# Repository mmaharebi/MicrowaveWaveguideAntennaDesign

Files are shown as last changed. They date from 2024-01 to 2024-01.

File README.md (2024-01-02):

# Microwave and Optical Design Lab Project 1

## Introduction
This project aims to provide a hands-on experience with the concepts and methods of matching in waveguide circuits, utilizing various discontinuities such as capacitive and inductive irises and E-plane posts. The designs were simulated and measured using HFSS software and AutoCAD.

## Experiments

### Experiment 1: Two-port iris structures
- **Objective**: Simulate and analyze the frequency response of a waveguide circuit with two assigned irises.
- **Steps**:
  1. Open AutoCAD files (`dwg1._3EXP_StudentID`) for iris designs.
  2. Simulate transmission and reflection coefficients in the 8-12 GHz range.
  3. Extract the circuit model using S-parameters and transmission line model.
  4. Use embedding-deembedding technique to compensate for extra lengths.

### Experiment 2: Open-ended waveguide antenna with an iris
- **Objective**: Measure reflection coefficient, compare results with Experiment 1, and analyze radiation patterns.
- **Steps**:
  1. Open AutoCAD files (`dwg1._3EXP_StudentID`) for iris designs.
  2. Measure reflection coefficient with absorbing boundary condition.
  3. Find the circuit model using measured reflection coefficient and transmission line model.
  4. Compare results with Experiment 1 and explain admittance differences.
  5. Calculate and plot realized gain pattern and beamwidth in E and H planes.

### Experiment 3: Matching the open-ended waveguide antenna with E-plane posts
- **Objective**: Match the waveguide antenna with metallic posts, analyze bandwidth, and radiation parameters.
- **Steps**:
  1. Open AutoCAD files (`dwg2._3EXP_StudentID`, `dwg3._3EXP_StudentID`) for post designs.
  2. Measure reflection coefficient with absorbing boundary condition.
  3. Use single-stub matching on the Smith chart to determine post distance and required admittance.
  4. Implement required admittance by designing post width using HFSS and plot admittance versus width curve.
  5. Plot frequency response, report 15 dB bandwidth, and optionally improve bandwidth with more posts.
  6. Calculate and plot realized gain pattern and beamwidth, comparing with unmatched antenna. Explain the effect of matching on radiation parameters.

## Submission
- Ensure that AutoCAD files for iris and post designs are named according to the provided format.
- Include a detailed report covering simulations, measurements, calculations, and plots for each experiment.
- Explain observations, comparisons, and the impact of matching on radiation parameters.

## How to Reproduce
1. Clone the repository: `git clone https://github.com/your-username/your-project.git`
2. Open AutoCAD files for iris and post designs.
3. Follow instructions in the README to reproduce each experiment.
4. Submit your results and report following the guidelines provided in the Submission section.

Feel free to reach out for any clarifications or assistance!

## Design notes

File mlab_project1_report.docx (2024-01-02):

به نام خدا

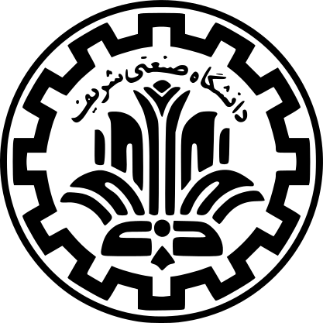
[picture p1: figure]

دانشگاه صنعتی شریف

دانشکده مهندسی برق

گزارش پروژه اول درس آزمایشگاه طراحی و ساخت مایکروویو و نوری

استاد درس:

دکتر علی بنایی

نگارش:

محمدمهدی محاربی

# آزمایش شماره 1

## الف

ساختار شبیه‌سازی در شکل 1 آورده شده است.

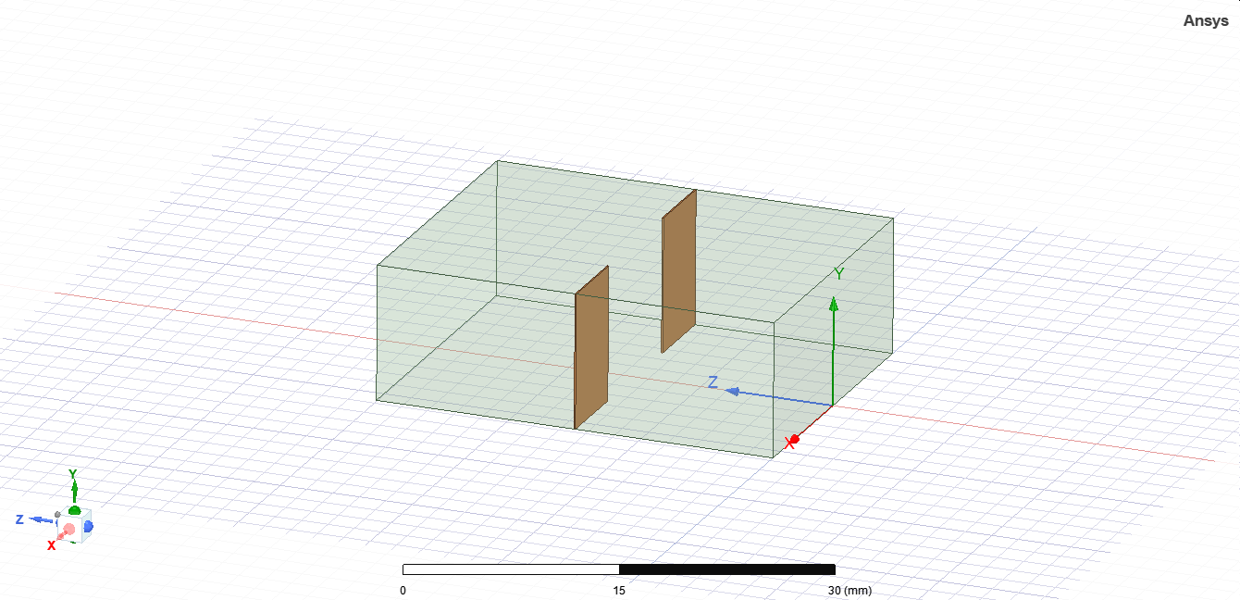
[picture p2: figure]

شکل 1 ساختار شبیه‌سازی آزمایش شماره 1

## ب

نمودار پاسخ فرکانسی اندازه افت عبوری و افت بازگشتی برحسب مقیاس dB ، پس از اعمال de-embedding بر پارامترهای پراکندگی در نمودارهای شکل 2 و شکل 3 آورده شده است.

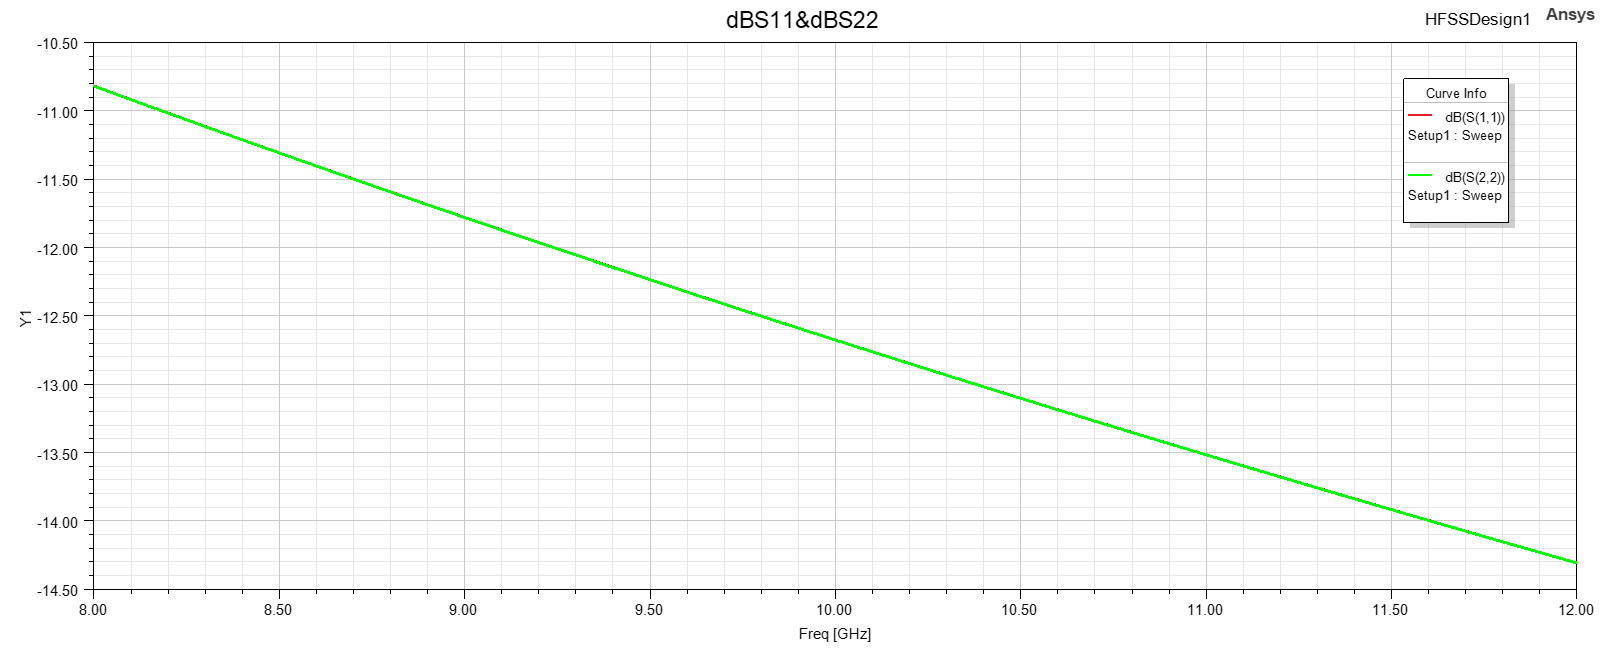
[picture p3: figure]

شکل 2 نمودار پاسخ فرکانسی اندازه افت بازگشتی برحسب مقیاس dB در پورت 1 و 2

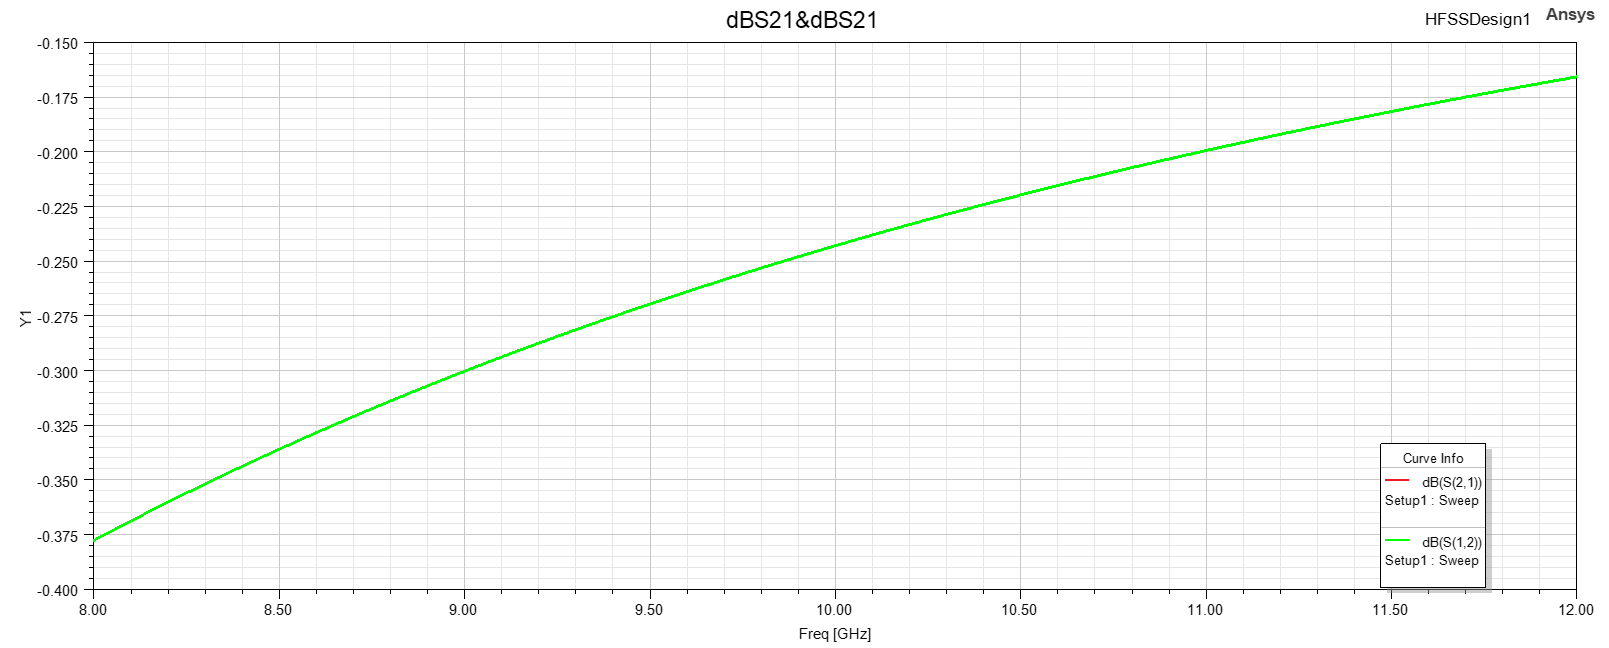
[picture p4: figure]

شکل 3 نمودار پاسخ فرکانسی اندازه افت عبوری برحسب مقیاس dB در پورت 1 و 2

همچنین، نمودار پاسخ فرکانسی فاز پارامترهای پراکندگی، برحسب درجه، در شکل 4 و شکل 5 قابل مشاهده است.

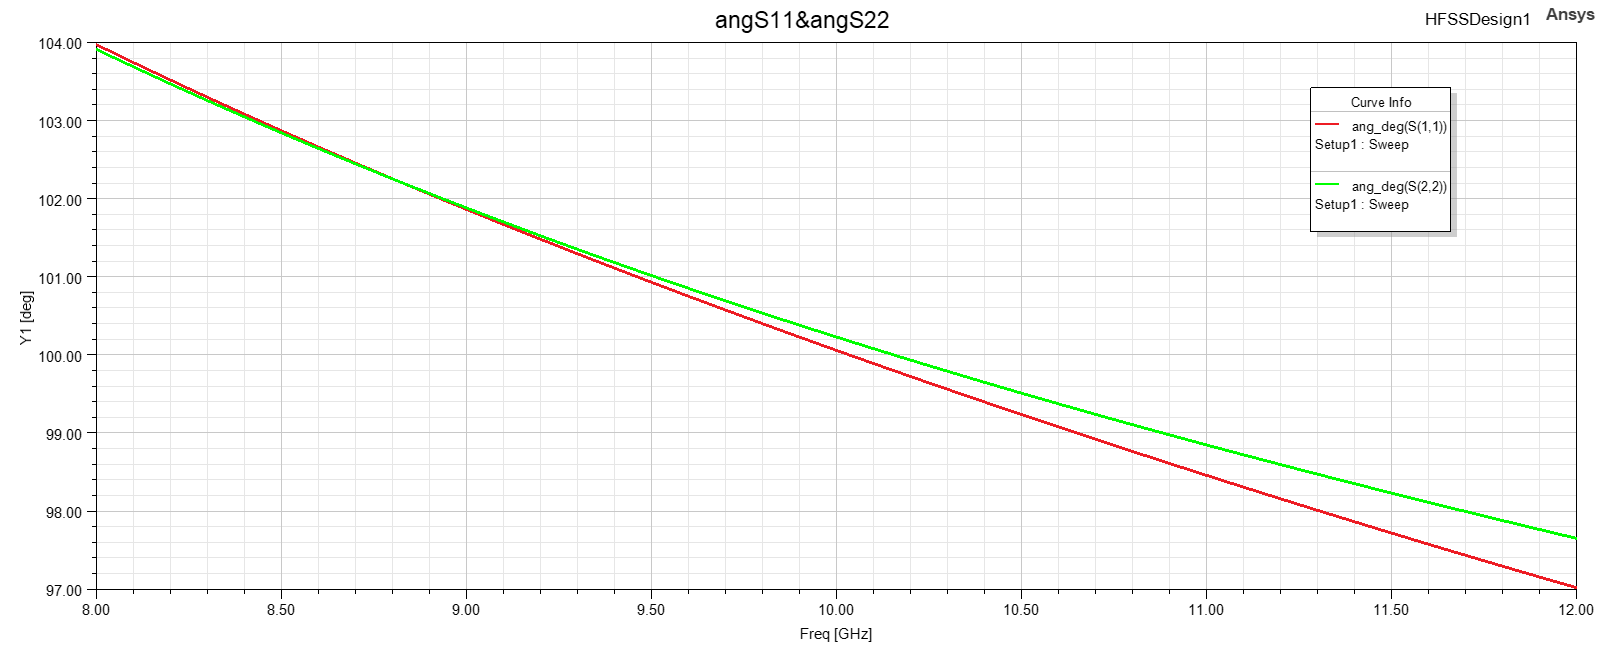
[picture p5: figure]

شکل 4 نمودار پاسخ فرکانسی فاز پارامترهای S_11 و S_22 برحسب درجه

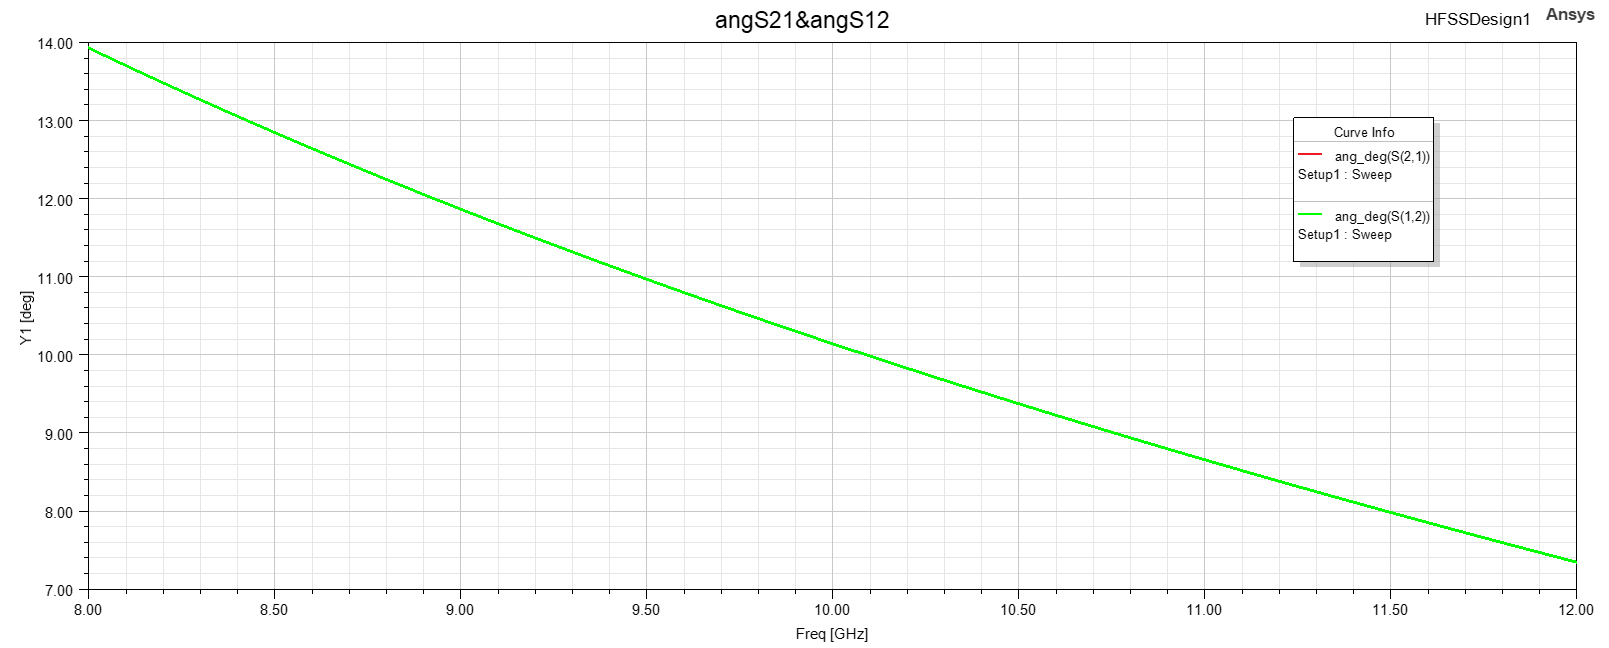
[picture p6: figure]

شکل 5 نمودار پاسخ فرکانسی فاز پارامترهای S_12 و S_21 برحسب درجه

## ج

مدار فشرده معادل با این ناپیوستگی به عنوان یک امپدانس (یا ادمیتانس) موازی در نظر گرفته می‌شود. با توجه به قابلیت استخراج پارامترهای امپدانس در نرم‌افزار HFSS، به‌جای تبدیل پارامترهای پراکندگی به پارامترهای امپدانس در خارج از محیط شبیه‌سازی، مقدار امپدانس Wave Portها در HFSS را برابر 50 Ω قرار داده شده و نمودارهای پاسخ فرکانسی بخش حقیقی و موهومی پارامتر Z_11 رسم شده است. این نمودارها در شکل 6 و شکل 7 قابل مشاهده است.

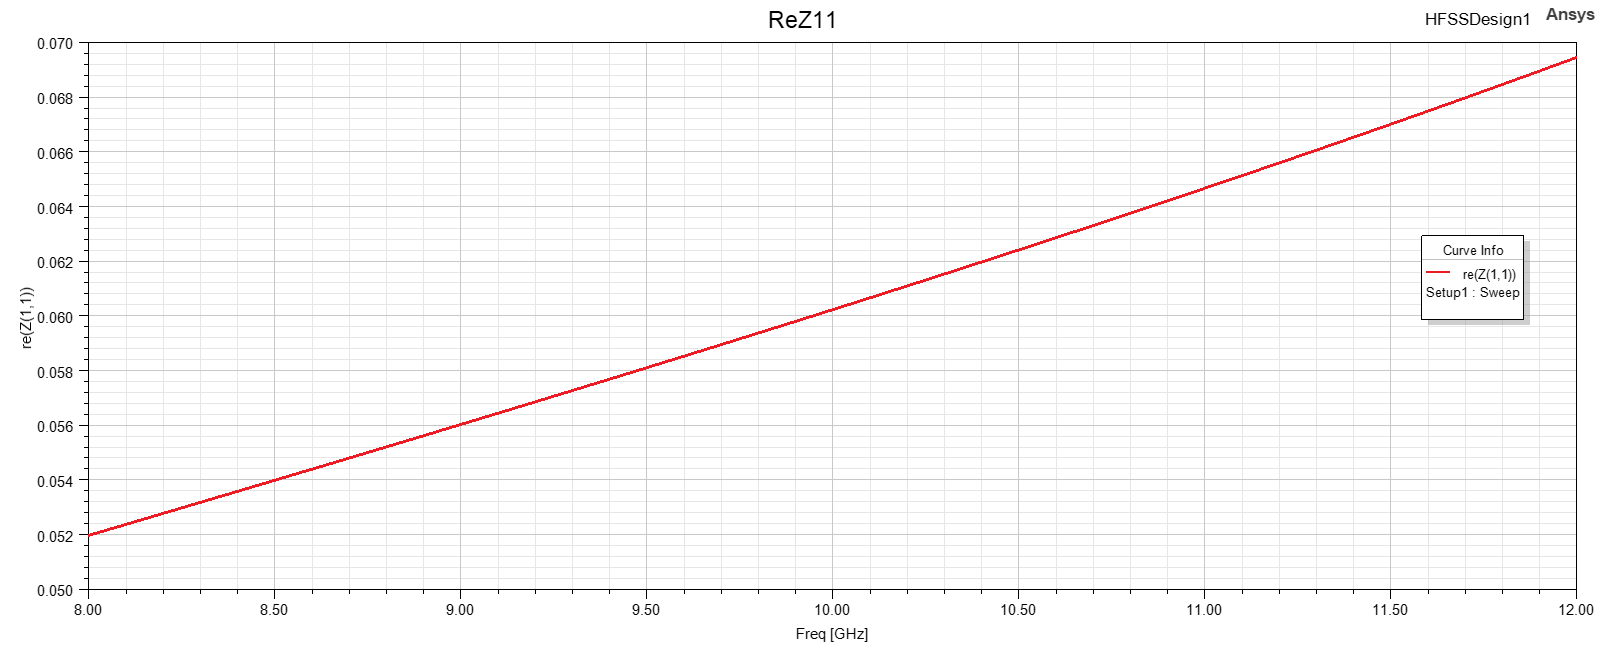
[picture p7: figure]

شکل 6 پاسخ فرکانسی بخش حقیقی پارامتر Z_11

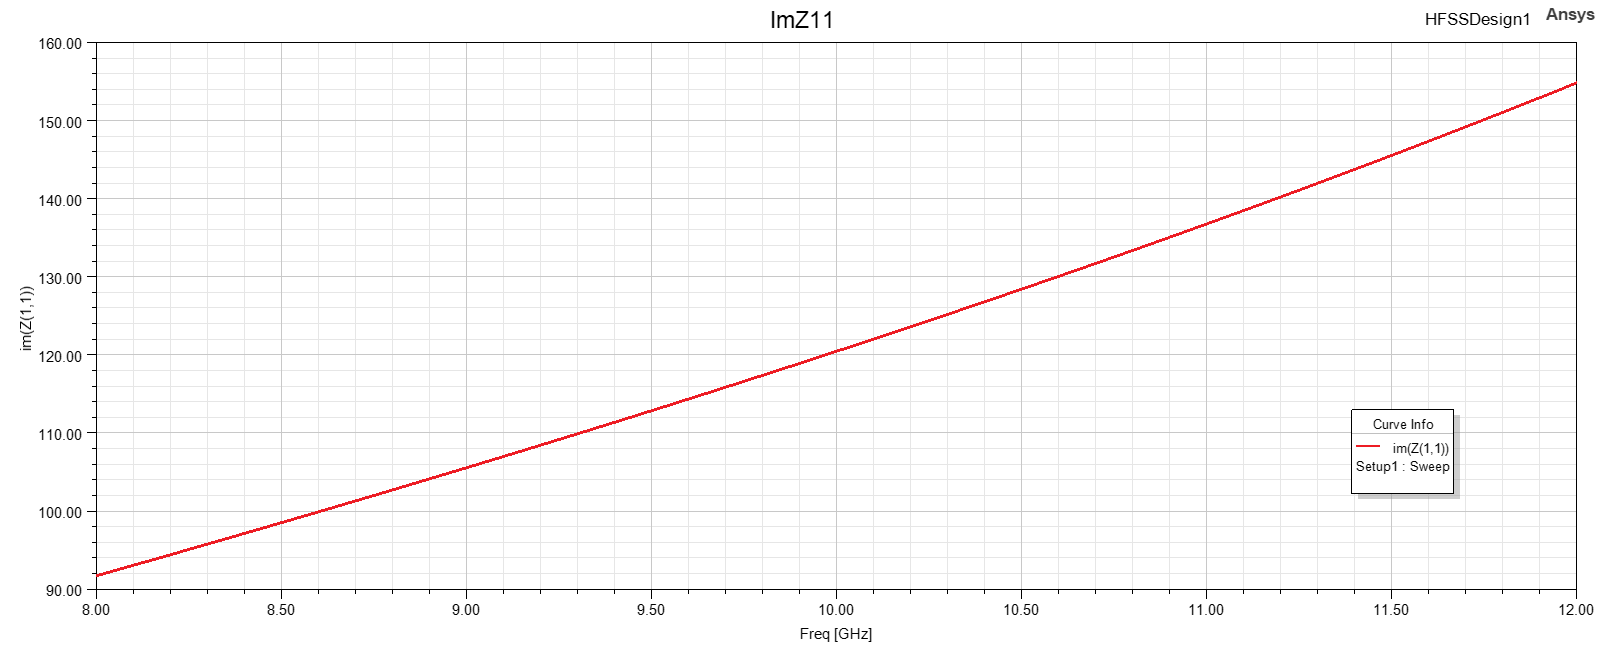
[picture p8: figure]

شکل 7 پاسخ فرکانسی بخش موهومی پارامتر Z_11

# آزمایش شماره 2

## الف

ساختار شبیه‌سازی در شکل 8 قابل مشاهده است.

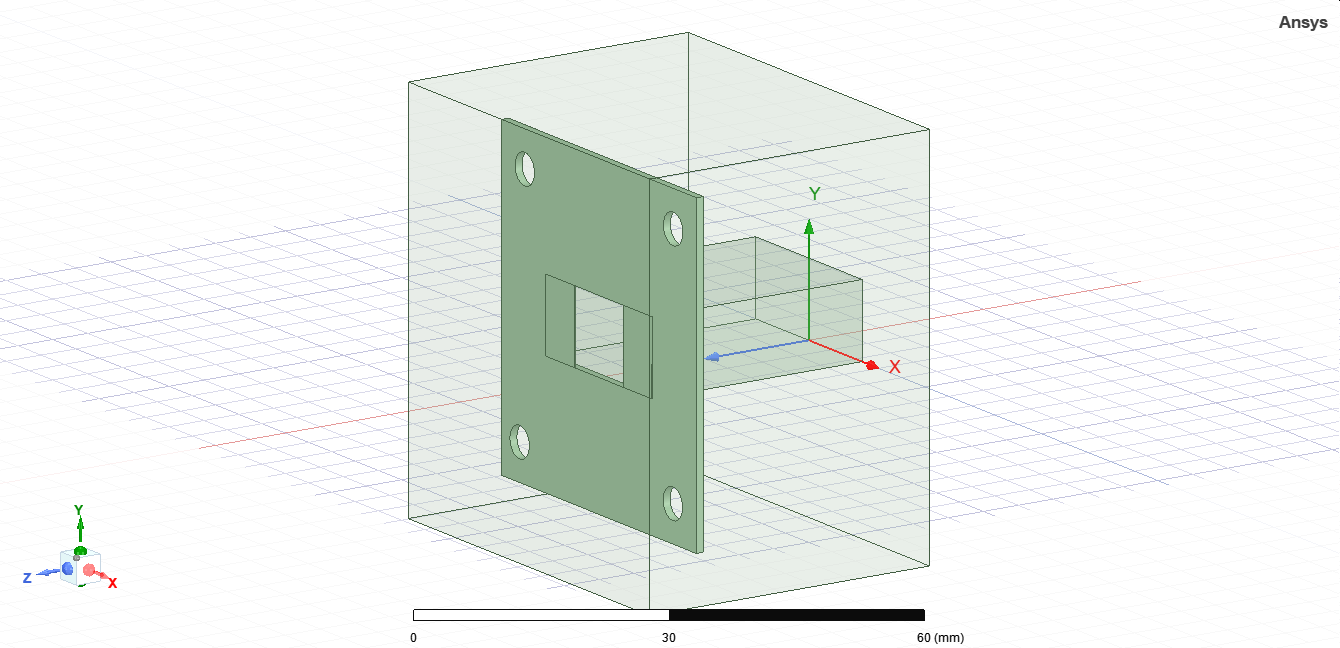
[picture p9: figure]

شکل 8 ساختار شبیه‌سازی آزمایش شماره 2

نمودارهای اندازه برحسب مقیاس dB و فاز برحسب درجه ضریب بازگشت موجبر (پارامتر S_11 در شکل 8) با انتهای باز همراه فلنج و روزنه در نمودارهای شکل 9 و شکل 10 قابل بررسی است.

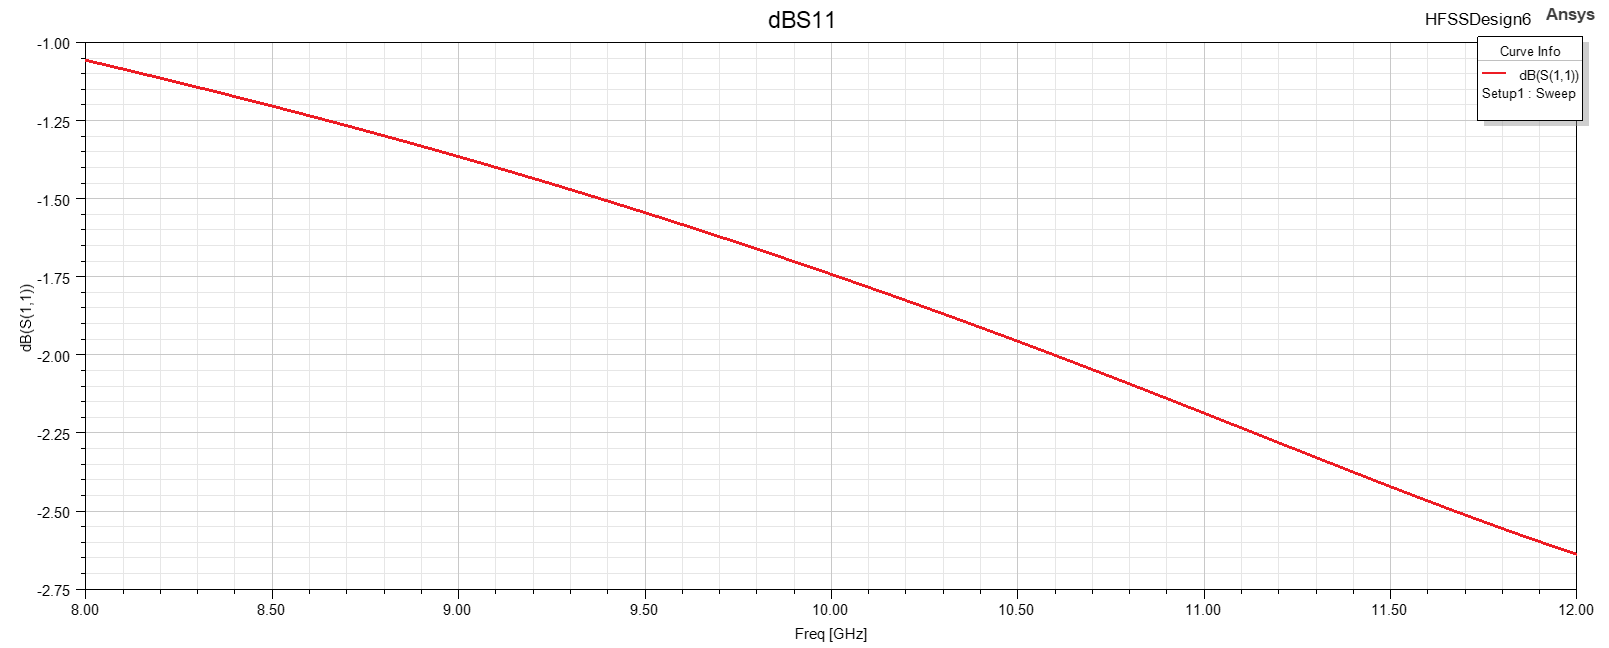
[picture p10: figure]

شکل 9 نمودار اندازه S_11 برحسب مقیاس dB

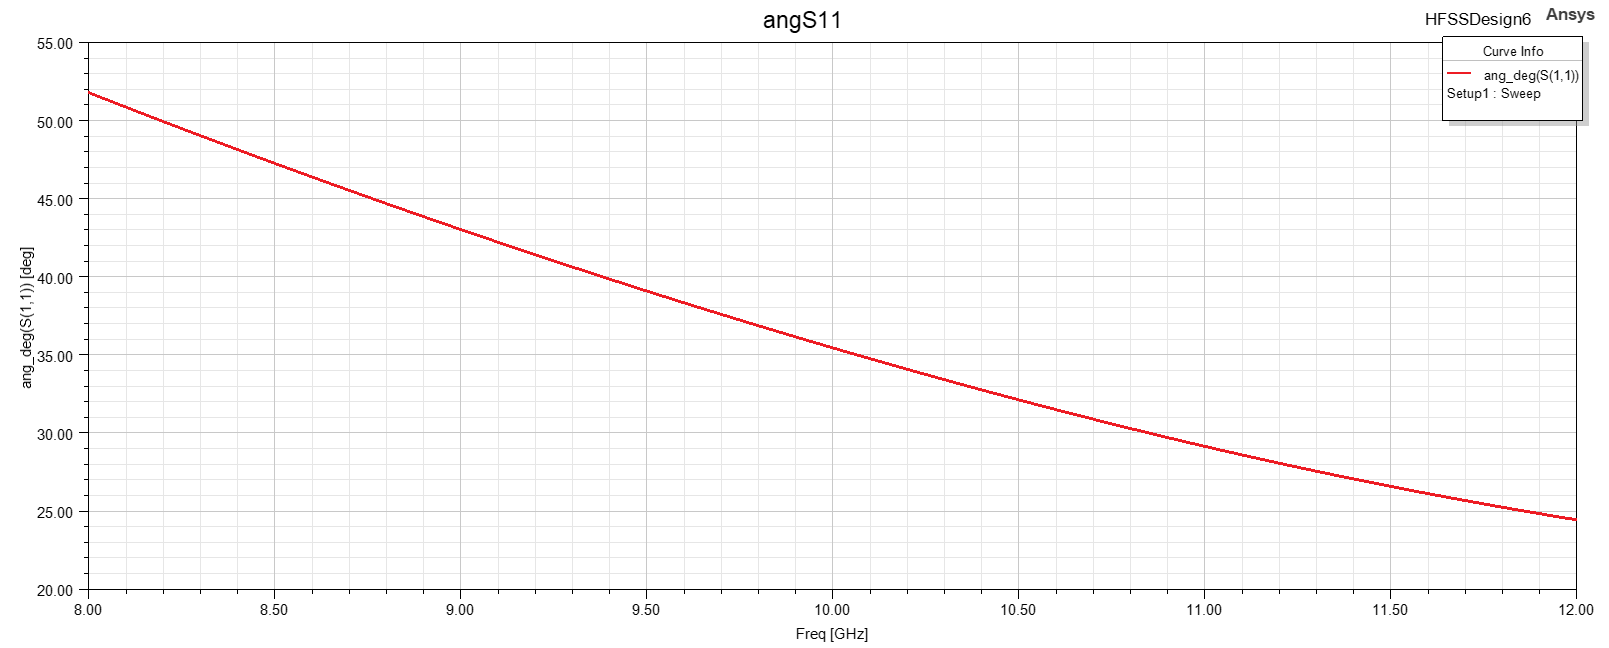
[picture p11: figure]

شکل 10 نمودار فاز S_11 برحسب درجه

## ب

با توجه به مشابهت این قسمت از این آزمایش با قسمت ب از آزمایش شماره 1، پارامتر Z_11 با توجه به توضیحات گفته شده استخراج شده است. نمودار پاسخ فرکانسی قسمت حقیقی و موهومی پارامتر Z_11 در شکل 11 و شکل 12 نمایش داده شده است.

شکل 11 نمودار پاسخ فرکانسی قسمت حقیقی پارامتر Z_11

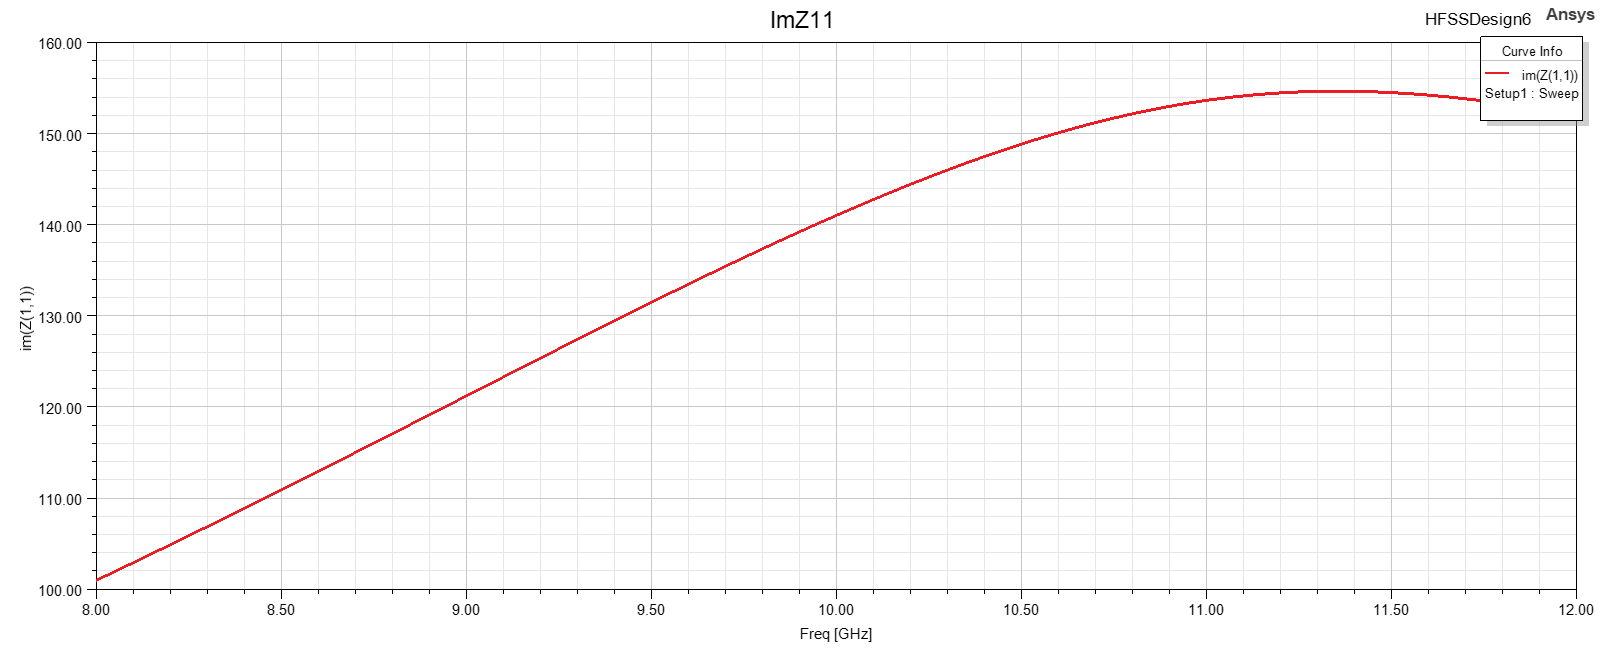
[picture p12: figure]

شکل 12 نمودار پاسخ فرکانسی قسمت موهومی پارامتر Z_11

## ج

همانطور که مشاهده می‌شود، نمودارهای شکل 11 و شکل 12 با نمودارهای شکل 6 و شکل 7 تفاوت دارند. همان‌طور که در نمودار شکل 12 دیده می‌شود، علاوه بر تفاوت مقادیر این نمودارها، رفتار این دو عنصر مدل‌شده با امپدانس نیز قدری با هم تفاوت دارد. در نمودار شکل 7 این‌طور به نظر می‌رسد که در تقریب مرتبه اول این عنصر می‌توان یک سلف موازی را جایگزین این عنصر نمود؛ چراکه تقریب خطی مدل ریاضی مناسبی برای این نمودار به نظر می‌رسد. اما نمودار شکل 12 این‌طور می‌نماید که در فرکانس‌های بالاتر، تقریب زدن فاز عنصر با رابطه‌ای خطی با فرکانس، منجر به خطای قابل ملاحظه‌ای می‌شود.

علت این تفاوت مشخصا در رفتار انتهای باز موجبر همراه فلنج نهفته است. چون اگر رفتار انتهای باز موجبر همراه فلنج، مانند مدار باز ایده‌آل بود، عنصر مورد بررسی از لحاظ مداری با امپدانس بی‌نهایت موازی شده و امپدانس مجموعه تفاوتی با امپدانس خود عنصر نمی‌کرد. در نتیجه، علت تفاوت در این دو آزمایش، انتهای باز موجبر با و یا بدون فلنج است که مانند مدارباز ایده‌آل رفتار نمی‌کند.

## د

نمودار الگوی تشعشعی بهره تحقق‌یافته آنتن موجبری با انتهای باز به همراه روزنه و فلنج، در نمودارهای شکل 13 و شکل 14، به ترتیب در E-Plane و H-Plane قابل مشاهده است.

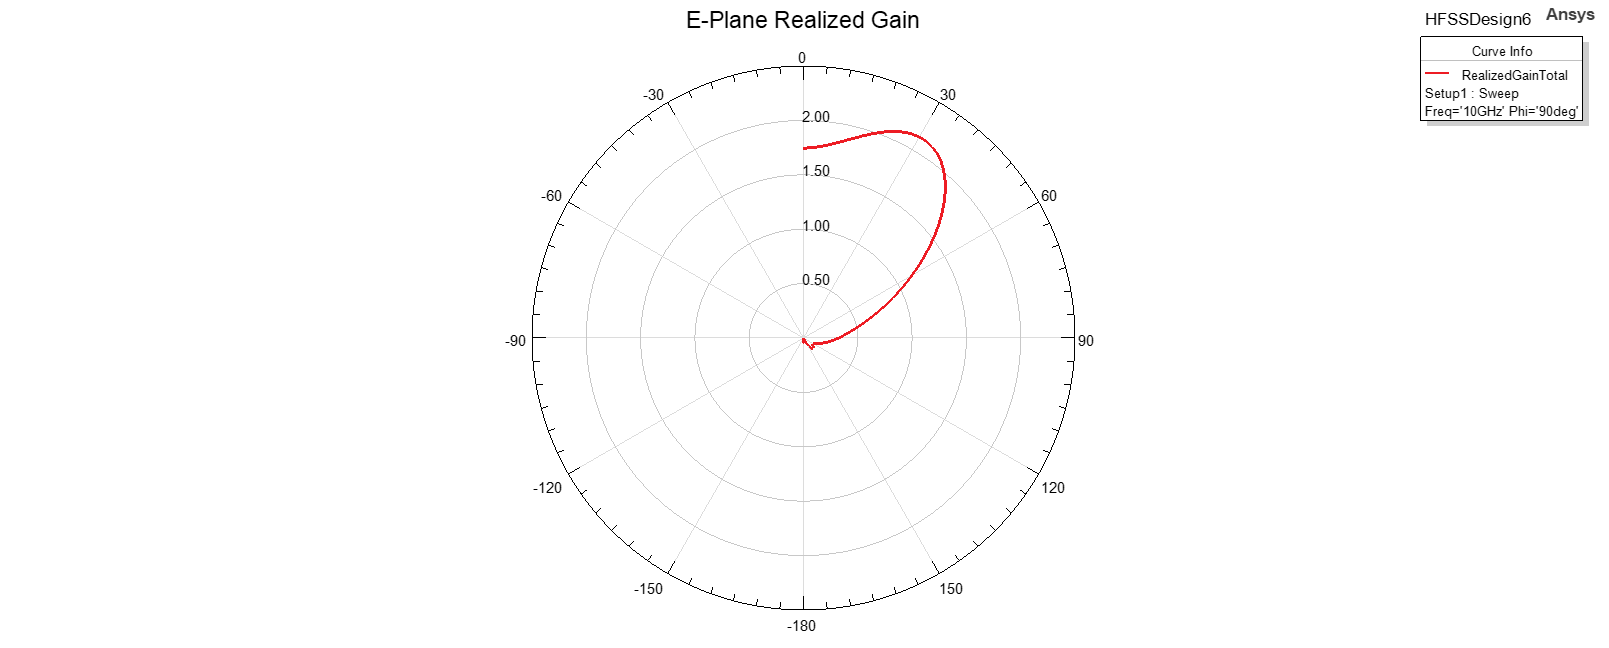
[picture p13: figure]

شکل 13 نمودار الگوی تشعشعی بهره تحقق‌یافته آنتن موجبری با انتهای باز به همراه روزنه و فلنج در E-Plane

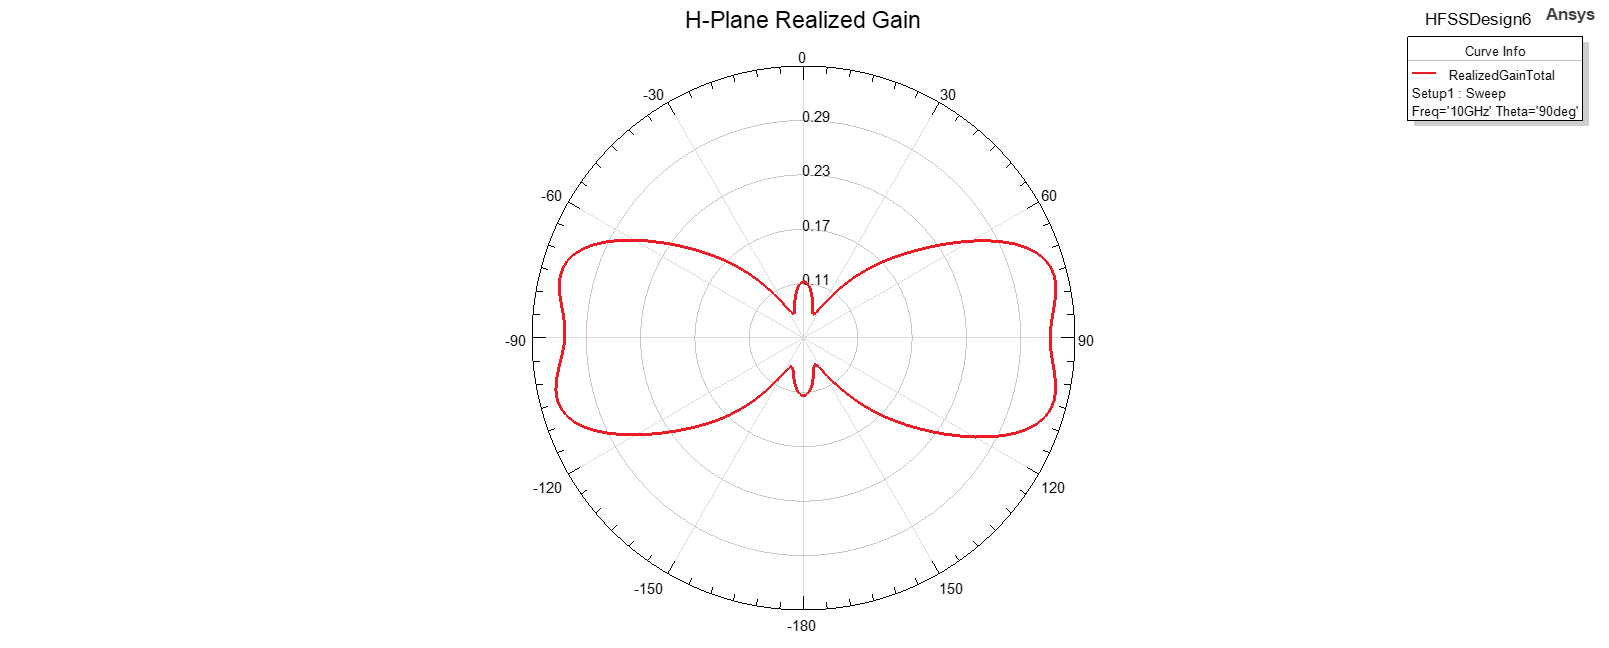
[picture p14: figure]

شکل 14 نمودار الگوی تشعشعی بهره تحقق‌یافته آنتن موجبری با انتهای باز به همراه روزنه و فلنج در H-Plane

برای اندازه‌گیری عرض پرتو، نمودارها برحسب مقیاس dB رسم شده است. دو نمودار الگوی تشعشعی بهره تحقق‌یافته آنتن موجبری با انتهای باز به همراه روزنه و فلنج برحسب مقیاس dB در E-Plane و H-Plane به ترتیب در نمودارهای شکل 15 و شکل 16 آورده شده است.

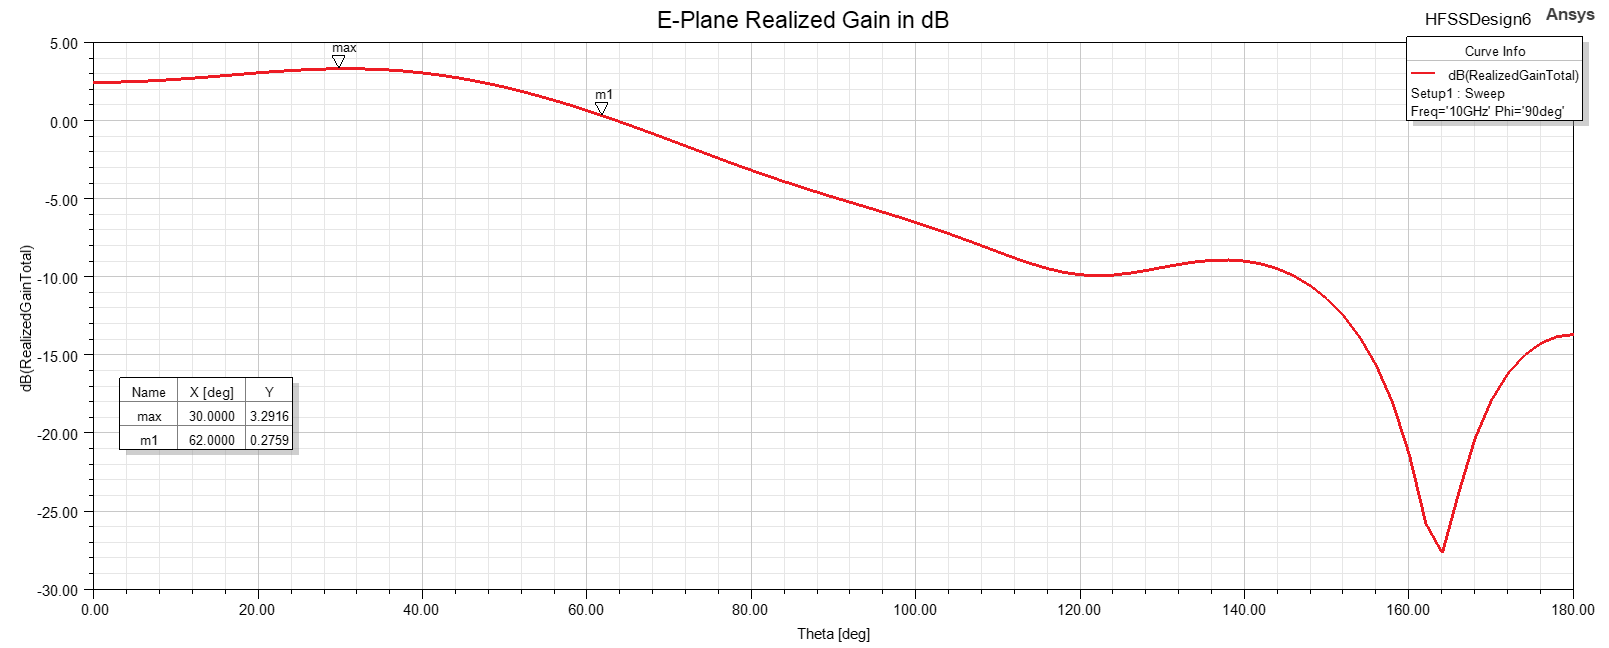
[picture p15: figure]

شکل 15 نمودار الگوی تشعشعی بهره تحقق‌یافته آنتن موجبری با انتهای باز به همراه روزنه و فلنج برحسب مقیاس dB در E-Plane

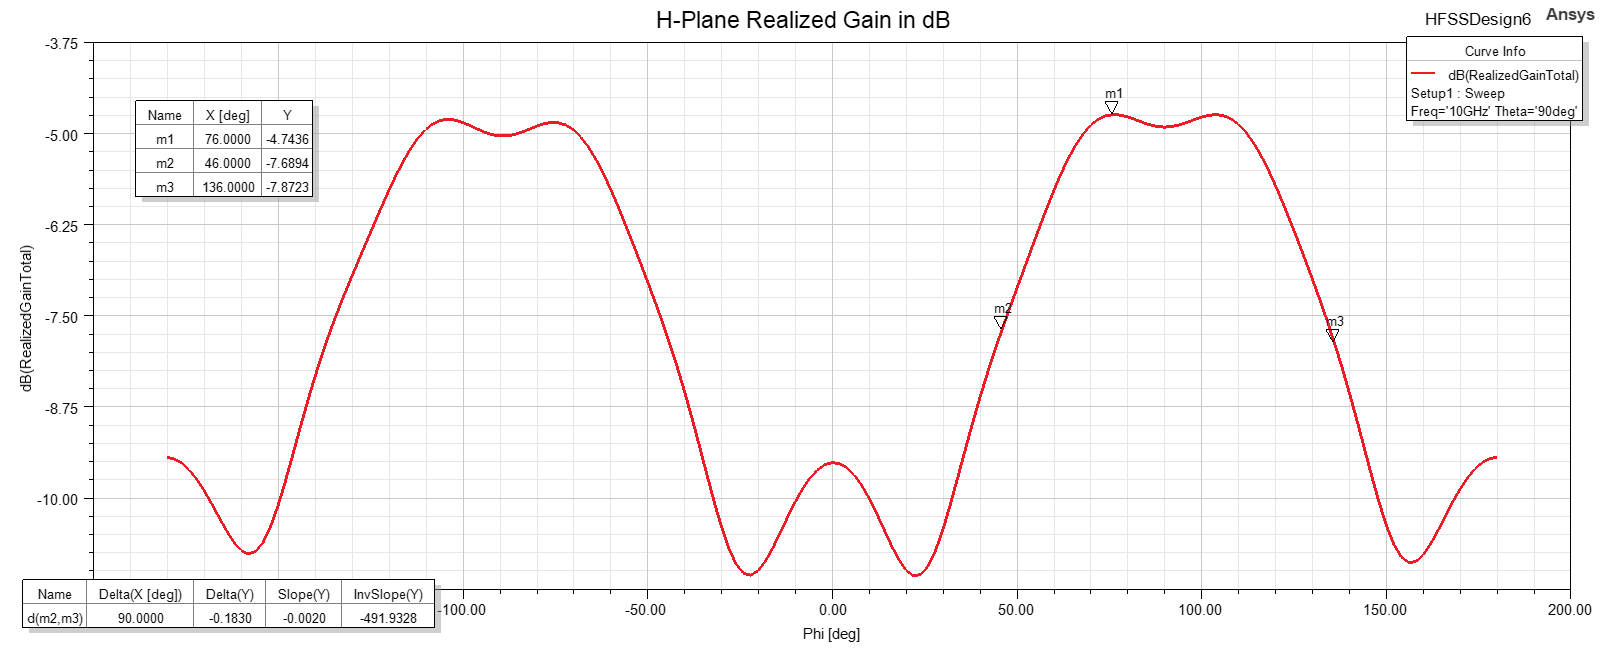
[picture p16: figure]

شکل 16 نمودار الگوی تشعشعی بهره تحقق‌یافته آنتن موجبری با انتهای باز به همراه روزنه و فلنج برحسب مقیاس dB در H-Plane

با توجه به نمودارهای شکل 15 و شکل 16، عرض بیم اندازه‌گیری شده در صفحات E-Plane و H-Plane به صورت جدول 1 است.

Beam-width in E-Plane | Beam-width in H-Plane
2×62°=124° | 90°

جدول 1 عرض بیم اندازه‌گیری شده در صفحات E-Plane و H-Plane

# آزمایش شماره 3

## الف

پاسخ فرکانسی ضریب انعکاس موجبر با روزنه و فلنج به صورت نمودار * است.

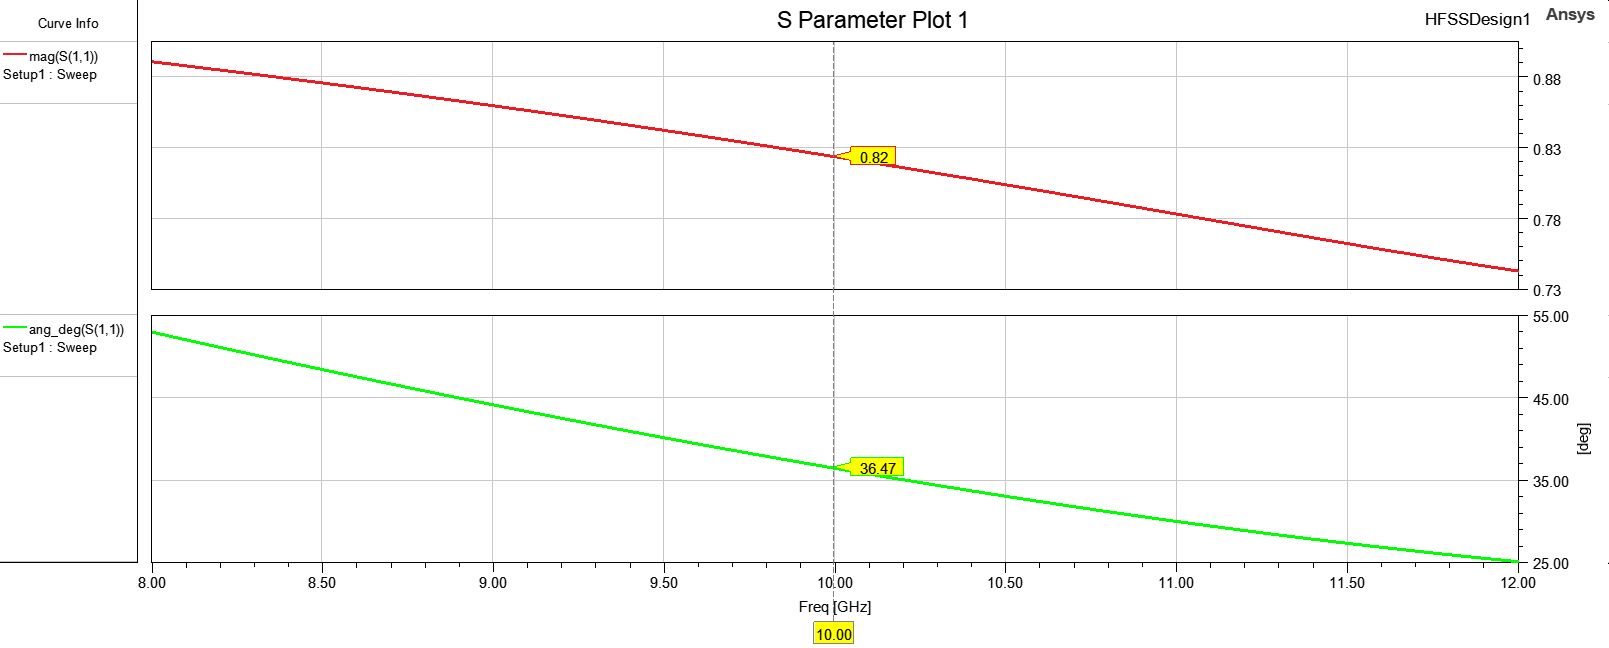
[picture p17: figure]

شکل 17 پاسخ فرکانسی ضریب انعکاس موجبر با روزنه و فلنج

## ب

در ادامه دو پاسخ به دست آمده آورده شده است. روش تطبیق در هر دو یکسان است. با استفاده از اسمیت-چارت موجود در نرم‌افزار ADS و وارد نمودن مقدار ضریب بازتاب و تنظیم فرکانس مربوطه، گره Load مشخص می‌شود. با حرکت روی یک خط سری (دایره به مرکز اسمیت-چارت) ضریب بازتاب به سمت مولد (حرکت ساعتگرد) به دایره y=1+jb منتقل می‌شود. نقاط تقاطع با این دایره مشخص شده و سپس با استفاده از یک خط اتصال کوتاه به سمت مرکز اسمیت-چارت، تطبیق اتفاق می‌افتد.

پاسخ نزدیک‌تر به بار به صورت شکل 18 و شکل 19 است.

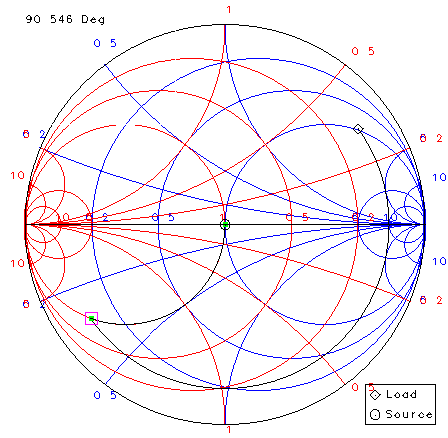
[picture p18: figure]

شکل 18 نمودار اسمیت-چارت پاسخ اول

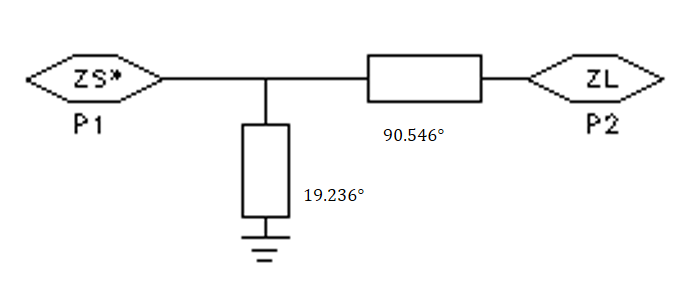
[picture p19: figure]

شکل 19 نمودار مدار پاسخ اول

جزئیات پاسخ دوم در شکل 20 و شکل 21 قابل مشاهده است.

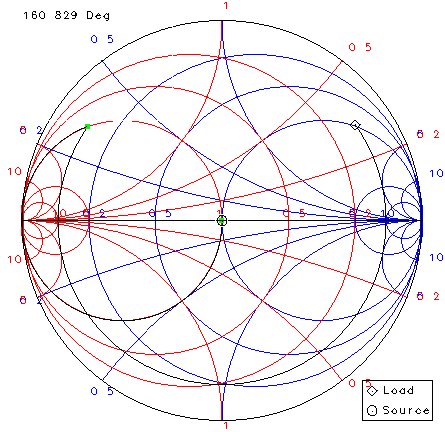
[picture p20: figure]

شکل 20 نمودار اسمیت-چارت پاسخ دوم

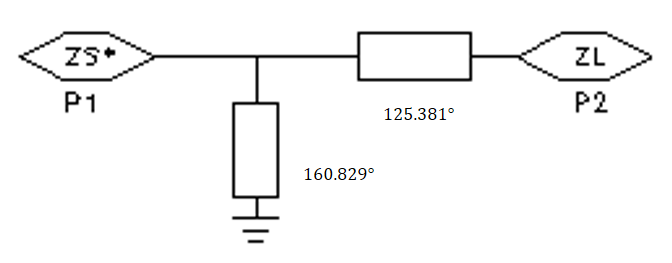
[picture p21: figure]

شکل 21 نمودار مدار پاسخ دوم

امپدانس استاب‌ها در جدول 2 قابل مشاهده است.

پاسخ اول | پاسخ دوم
Z_(stub) =jZ_0 tan19.236°=j50×0.3357 Ω | Z_(stub) =jZ_0 tan160.829°=-j50×0.3477 Ω

جدول 2 امپدانس استاب‌ها

## ج

نمودار امپدانس تیغه برحسب عرض تیغه به صورت شکل 22 است.

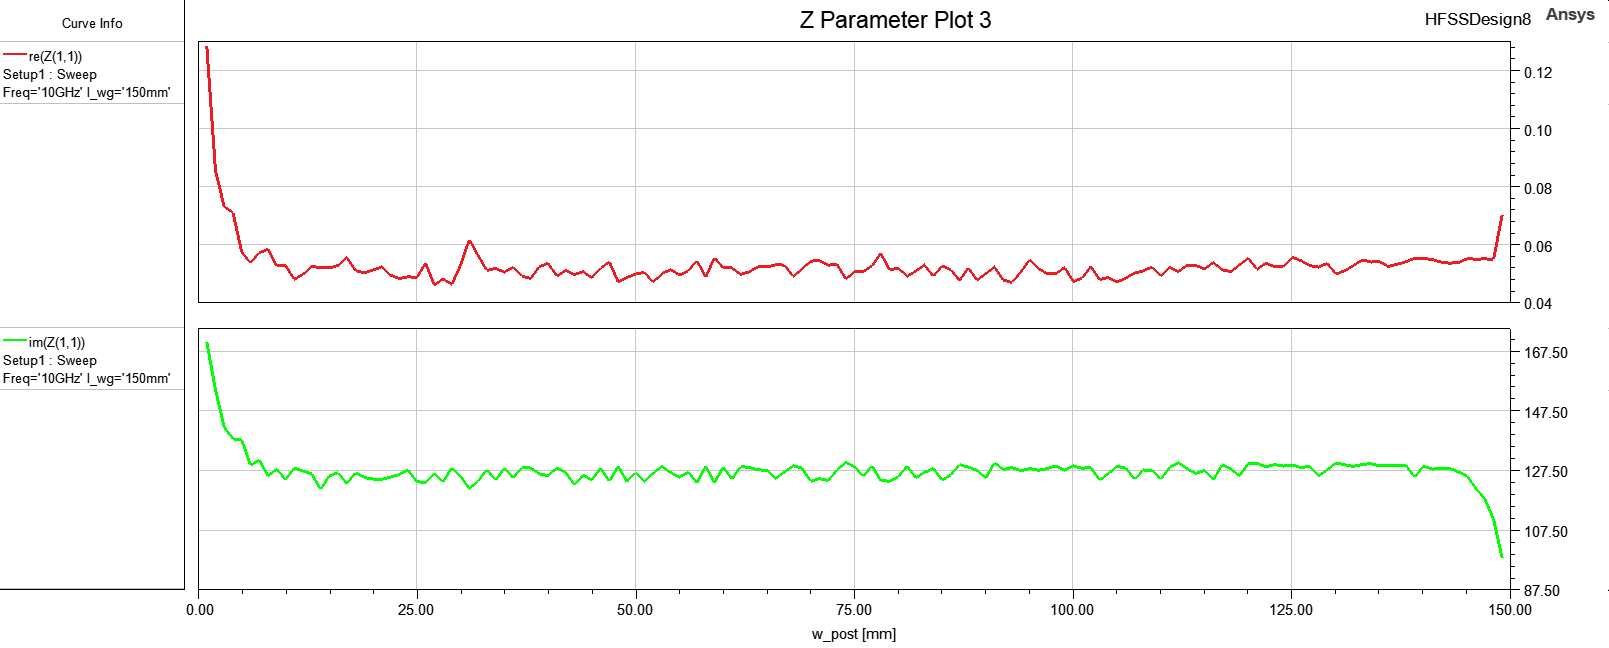
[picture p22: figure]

شکل 22 نمودار امپدانس تیغه برحسب عرض تیغه

همان‌طور که از مقایسه شکل 22 و جدول 2 بر می‌آید، امکان تحقق امپدانس محاسبه شده برای استاب‌ها با امپدانس تیغه ممکن نیست.

با سعی و خطا و آزمایش عرض‌های مختلف تیغه و فاصله‌های متفاوت، نمودار شکل 23 حاصل شده است.

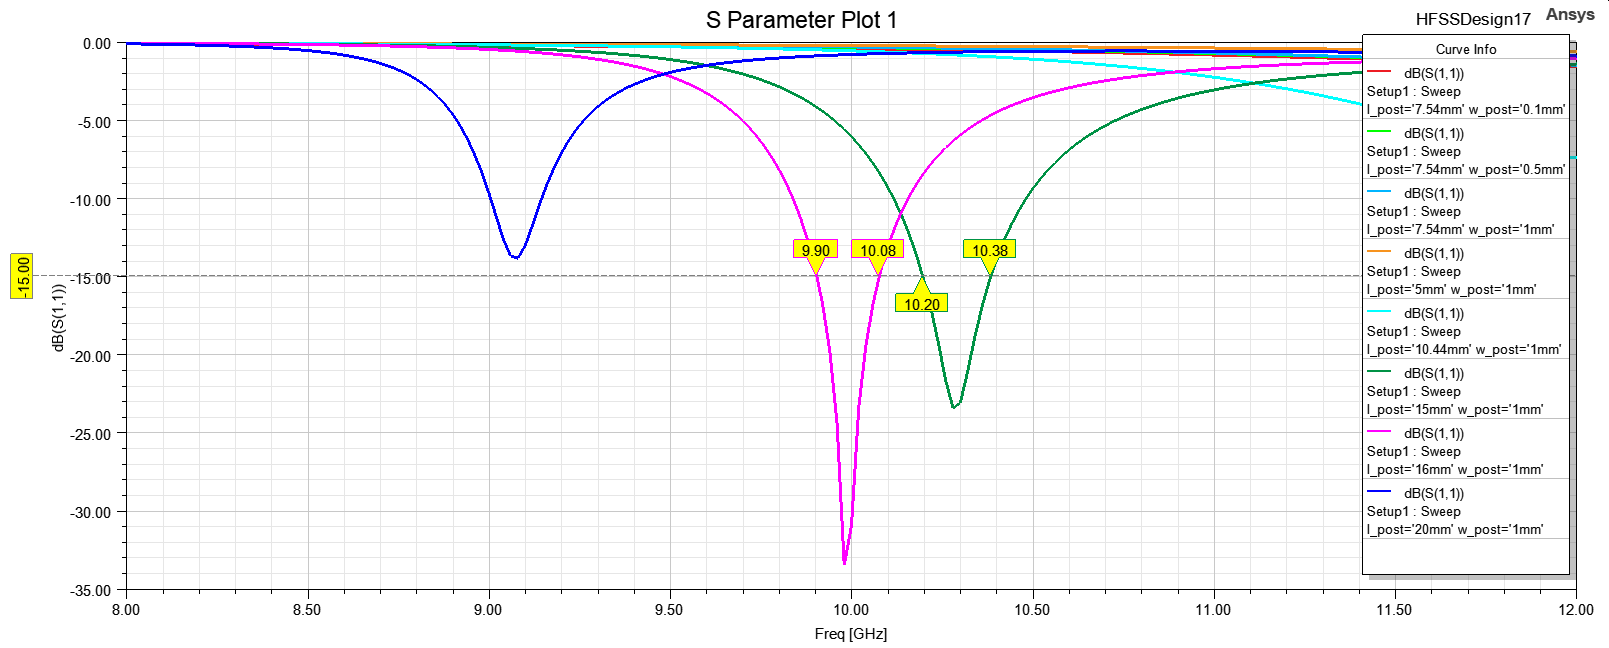
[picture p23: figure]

شکل 23 نمودار ضریب بازگشت برای عرض‌ها و فاصله‌های مختلف تیغه

عرض و فاصله مناسب تیغه در جدول 3 قابل مشاهده است. همانطور که از نمودار شکل 23 قابل مشاهده است، پهنای باند معادل، برابر 108 MHz است.

عرض مناسب تیغه | فاصله مناسب تیغه از دهانه موجبر
1 mm | 16 mm

جدول 3 عرض و فاصله مناسب تیغه

شمای ساختار مورد شبیه‌سازی به همراه وضعیت تیغه در * قابل مشاهده است.

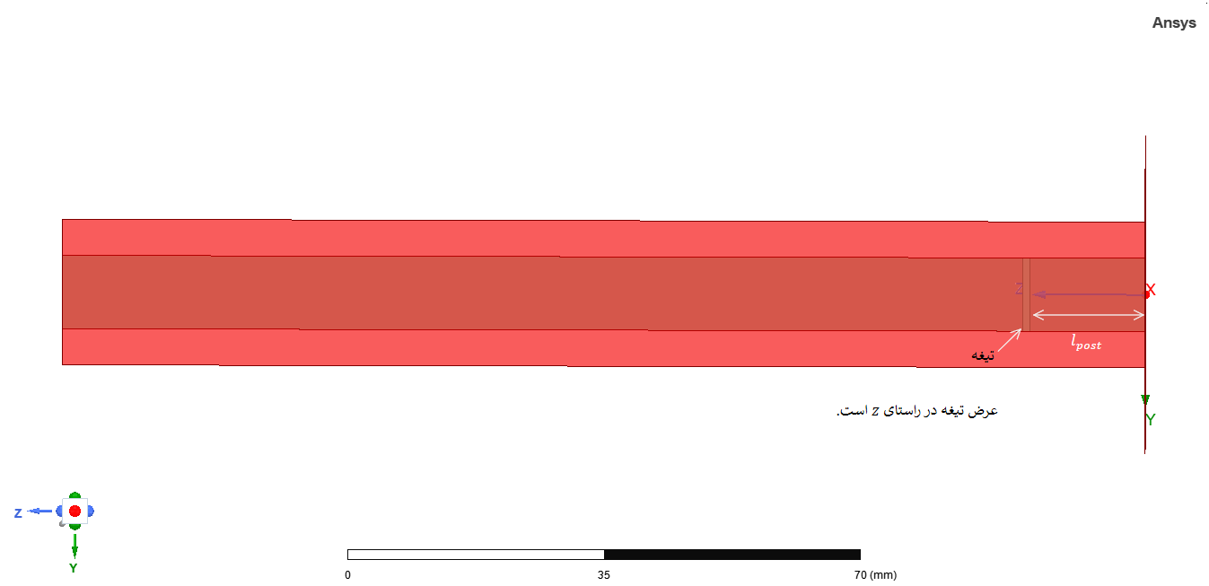
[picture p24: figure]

شکل 24 شمای ساختار مورد شبیه‌سازی و وضعیت تیغه

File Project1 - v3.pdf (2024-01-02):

به نام خدا
پروژه اول آزمایشگاه طراحی و ساخت مایکروویو و نوری «آشنایی با تطبیق در مدارات موجبری»
تاریخ آخرین ویرایش: /۱۲ ۱۴۰۱/۰۲ نیمسال دوم سال تحصیلی ۱۴۰۱-۱۴۰۰
مقدمه
موجبرهای فلزی توخالی یکی از محیط های انتشار امواج الکترومغناطیسی هستند. در این موجبرها
است. با توجه به عدم امکان تعریف | 10TE | امکان انتشار امواج با مود TEM وجود ندارد. اولین مود انتشاری، مود
ولتاژ و جریان در چنین محیط انتشاری، نمی توان برای آن مدل گسترده ی خط انتقال در نظر گرفت. در عین حال می توان در یک خط انتقال فرضی، تناظری بین میدان های Ey و Hx این مود و ولتاژ و جریان برقرار کرد و
ً | مدارهای موجبری را با متناظر خط انتقالی آن ها نمایش داد. حسن این کار استفاده از روش
هایی است که قبلا
برای تطبیق امپدانس با خطوط انتقال بکار می بردیم و می توانند در اینجا نیز به کمک ما بیایند. برای آگاهی از نحوه ی متناظرسازی مدل خط انتقالی به کتاب مهندسی مایکروویو پوزار ( فصل ۴ بخش ۱ ویرایش چهارم) مراجعه نمایید. در ادامه به شرح پروژه خواهیم پرداخت. معرفی چند ناپیوستگی
در درس مهندسی مایکروویو، با روزنه های سلفی و خازنی به عنوان یک ناپیوستگی در موجبرهای مستطیلی آشنا شده اید. شکل این روزنه ها و معادل مداری آن ها در مدل خط انتقال متناظر، به صورت شکل ۱ است.


در این پروژه، از روزنه های متقارن استفاده خواهیم کرد و فاصله ی مشخص روی شکل ۱ را عرض روزنه مینامیم. برای هر شخص، نوع روزنه و عرض آن مشخص شده است. در آزمایش هایی که در ادامه تعریف میشوند، هر فرد باید از روزنه ی خود استفاده کند.

شکل :۱ روزنههای سلفی و خازنی در موجبرمستطیلی

است. این | ١ | یک ناپیوستگی دیگر که در این پروژه از آن استفاده خواهید کرد، تیغهی فلزی عمودی صفحهی E
ناپیوستگی به صورت شکل ۲ است.


همانطور که در شکل واضح است، این تیغه ی نازک دقیقا در وسط ضلع بزرگتر موجبر در صفحه ی E قرار میگیرد. درجه ی آزادی طراحی شما، عرض این تیغه است. در ادامه، به شرح آزمایش هایی که باید انجام دهید، پرداختهایم. آزمایش شماره ۱
در ساختار یک موجبر 90WR، روزنه ی خود را به شکل زیر بسازید. تمامی روزنه ها و تیغهها، از ورقههای مسی به ضخامت µm100 ساخته میشوند. لذا در شبیهسازی خود این ضخامت را در نظر بگیرید.


الف) طرفین این مدار موجبری به ژنراتور و بار منطبق بسته می شوند. با فرض اینکه موجبر و روزنه ها از مس ساخته شده اند، مدل مناسب شبیهسازی را ایجاد کنید. ب) پاسخ فرکانسی افت عبوری و افت بازگشتی را در بازه ی فرکانسی GHz8-12 رسم نمایید. ج) با کمک منحنیهای در اختیار 11S و 21S،اقدام به استخراج مدل مداری روزنه ی خود کنید. در این مدل مداری، فرض کنید که امپدانس مشخصهی مدل خط انتقالی متناظر برابر Ω50 باشد.

1 E-plane Post

شکل :۲ تیغهی عمودی صفحهی E

شکل :۳ آزمایش روزنههای سلفی و خازنی به صورت دو دهانهای

توجه: در روند پیدا کردن مدل مداری، باید با کمک embedding-de، طول بخش های اضافه را جبران کنید تا ادمیتانس اشتباه محاسبه نکنید. توجه کنید که طول بازوهای اضافه باید حداقل ۹۰ درجه باشد تا دامنهی میرا نشده ی مودهای دیگر، در محاسبات پارامترهای پراکندگی، خطای قابل توجهی ایجاد نکنند. آزمایش شماره ۲
در این آزمایش، روزنه ی خود را در انتهای یک موجبر 90WR قرار دهید. برای این منظور، یک ورقه ی مسی
، این ورقه به انتهای موجبر | ٢ | که روزنهی هر فرد روی آن ایجاد شده است ساخته خواهد شد و به کمک فلنج
90WR اضافه خواهد شد. روزنه خود را به شکل زیر به موجبر 90WR اضافه کنید:


در دهانه ی مشخ ص، باید Port قرار دهید. ابعاد فلنج در انتهای دستور کار مشخص شده است. الف) ضریب انعکاس موجبر با انتهای باز همراه با فلنج و روزنه خود را برای فرکانس داده شدهاندازه گیری کنید (باید با شرط مرزی جذبی برای تابش و با کمک embedding-de این کار را انجام دهید). ب) پس از اندازه گیری ΓL انتهای موجبر همراه فلنج و روزنه در فرکانس داده شده، میتوانیم برای خروجی دهانه ی باز موجبر، یک مدل مداری پیدا کنیم. با استفاده از ΓL اندازه گیریشده، مدل مداری این ساختار را پیدا کنید. مشابه آزمایش قبلی، فرض کنید که امپدانس مشخصه ی مدل خط انتقالی متناظر برابر Ω50 باشد. ج) نتیجه این آزمایش را با آزمایش ۱ مقایسه کرده و دلیل تفاوت مقدار ادمیتانس محاسبهشده را دقت توضیح دهید. آیا نتیجهی بدست آمده مورد انتظارتان است؟
آنتن موجبری با انتهای باز به همراه روزنه و فلنج را در صفحات | ٣ | د) الگوی تشعشعی بهره ی تحققیافته ی
ی آن را محاسبه نمایید. | ٤ | E و H به dB رسم نموده و عرض پرتو

2 Flange
3 Realized Gain Pattern 4 Beamwidth

شکل :۴ روزنه در انتهای یک موجبر به عنوان آنتن

آزمایش شماره ی ۳
در این آزمایش، با قرار دادن حداقل یک تیغهی فلزی عمودی plane-E، می خواهیم آنتن ساخته شده توسط انتهای باز موجبر را تطبیق کنیم. برای این منظور، مانند شکل زیر، هندسه مورد نظر خود را طراحی کنید. طول این موجبر را mm 150بگیرید و تیغه های مسی را با ضخامت µm 100 بسازید.


الف) به این منظور لازم است ابتدا ضریب انعکاس موجبر با انتهای باز همراه با فلنج و روزنه را برای فرکانس داده شده اندازه گیری کنید (باید با شرط مرزی جذبی برای تشعشع با کمک embedding-de این کار را انجام دهید).
ب) محل بار دیده شده در دهانه ی موجبر را در نمودار اسمیت مشخص کرده و به کمک روش تطبیق تک استابی که در دروس قبلی با آن آشنا شده اید، فاصلهی تیغه از دهانه ی خروجی موجبر و ادمیتانس مورد نیاز برای تطبیق آن را تعیین کنید. در این طراحی، سعی و خطا قبل قبول نبوده و باید به دقت و با استفاده از نمودار اسمیت تمامی مراحل را طی کنید. به خاطر فرایند ساخت خلاقانه ای که برای این ساختار در نظر گرفته شده است، محدودیتی روی محل تیغه ندارید. ج) حال ادمیتانس مورد نیازتان را توسط تیغهی عمودی پیادهسازی کنید. برای این منظور، ادمیتانس این تیغه را برحسب عرض آن در نرم افزار HFSS رسم کرده و مقدار عرض مطلوب خود را انتخاب کنید. سعی و خطا برای تعیین عرض تیغه قابل قبول نیست (توجه می کنیم که باز هم باید embedding-de مناسب انجام داد تا در محاسبات ادمیتانس خطا نداشته باشیم.). -توجه: در اندازه گیری این ادمیتانس، می توانید از روش های مختلفی مثل آزمایش های تک دهانهای و یا
دو دهانه ای استفاده کنید. از هر روشی استفاده می کنید، باید جزئیات روش خود را به دقت شرح دهید. د) پس از طراحی تیغه، پاسخ فرکانسی مجموعه را در بازه ی GHz8-12 رسم نموده و پهنای باند dB15 را گزارش نمایید.

شکل :۵ تطبیق انتهای باز موجبر 90WR به همراه فلنج و روزنه با چند تیغه

ه) (اختیاری) با افزودن چند تیغهی دیگر، سعی کنید که آنتن خود را در پهنای باند بیشتری تطبیق کنید. پهنای باند dB15 ساختار خود را گزارش کنید. توجه کنید که مانند قسمت های قبل، سعی و خطا مجاز نیست و باید روند طراحی خود را به دقت توضیح دهید.
آنتن موجبری با انتهای باز (آزمایش ۲) و آنتن تطبیقشده را در | ٥ | د) الگوی تشعشعی بهره ی تحققیافته ی
دو آنتن را مقایسه نمایید. آیا تطبیق پارامترهای تابشی آنتن | ٦ | صفحات E و H به dB رسم نموده و عرض پرتوی
را تحت تاثیر قرار داده است؟ توضیح دهید.
- توجه: در تمامی قسمت های قبل، پس از طراحی نهایی، میتوانید با تغییر بسیار کم پارامترهای طراحی شده، به بهینهسازی پاسخ خود بپردازید. قاعدتا این کار ایرادی ندارد و سعی و خطای صرف بدون طراحی اولیه قابل قبول نیست.
- نقشه ی هندسی دیافراگم (های) طراحی شده را با فرمت زیر ارسال نمایید: روزنهی خود که روی خروجی قرار می گیر د: dwg1._3EXP_StudentID تیغه طراحی شده به روش تک استاب: dwg2._3EXP_StudentID تیغه طراحی شده به روش چند استاب: dwg3._3EXP_StudentID چند نکته
-برای ساخت این ساختار، یک موجبر 90WR که از /2a = x بریده شده است را استفاده میکنیم. تیغهی طراحی شده ی شما بین این دو قسمت پیچ خواهد شد. لذا سعی کنید که تیغه را به فرمتی که روی سامانه قرار گرفته است طراحی کنید.
- لازم است طراحی ورقه های مسی دارای روزنه و تیغه خود را در قالب داده شده با نرم افزار AutoCAD کشیده و تحویل دهید تا پس از ساخت، در حضور خودتان (در صورت رفع محدودیت ها) پاسخ فرکانسی 11S و
اندازه گیری شوند. نمونهای از شکل روزنه ی معتبر و تیغهی مناسب در سامانه برای شما قرار داده شده است. | 21S
- ابعاد فلنج و موجبر به صورت زیر هستند. فایل AutoCAD این ساختار نیز در سامانه قرار گرفته است.


5 Realized Gain Pattern
6 Beamwidth

شکل :۶ ابعاد موجبر و فلنج آن؛ همه طولها به mm هستند و قطر سوراخها گزارش شده است.

شما باید لایه ی قرمز رنگ را برای ساخت تیغههای صفحه ی E طراحی کنید و مانند شکل ،۶ تی غههای خود
را قرار دهید. همچنین دهانه ی فلنج نیز به شکل ۶ است که باید روزنه های خود را به شکل آن با ابعاد من اسب روزنه، طراحی کنید.

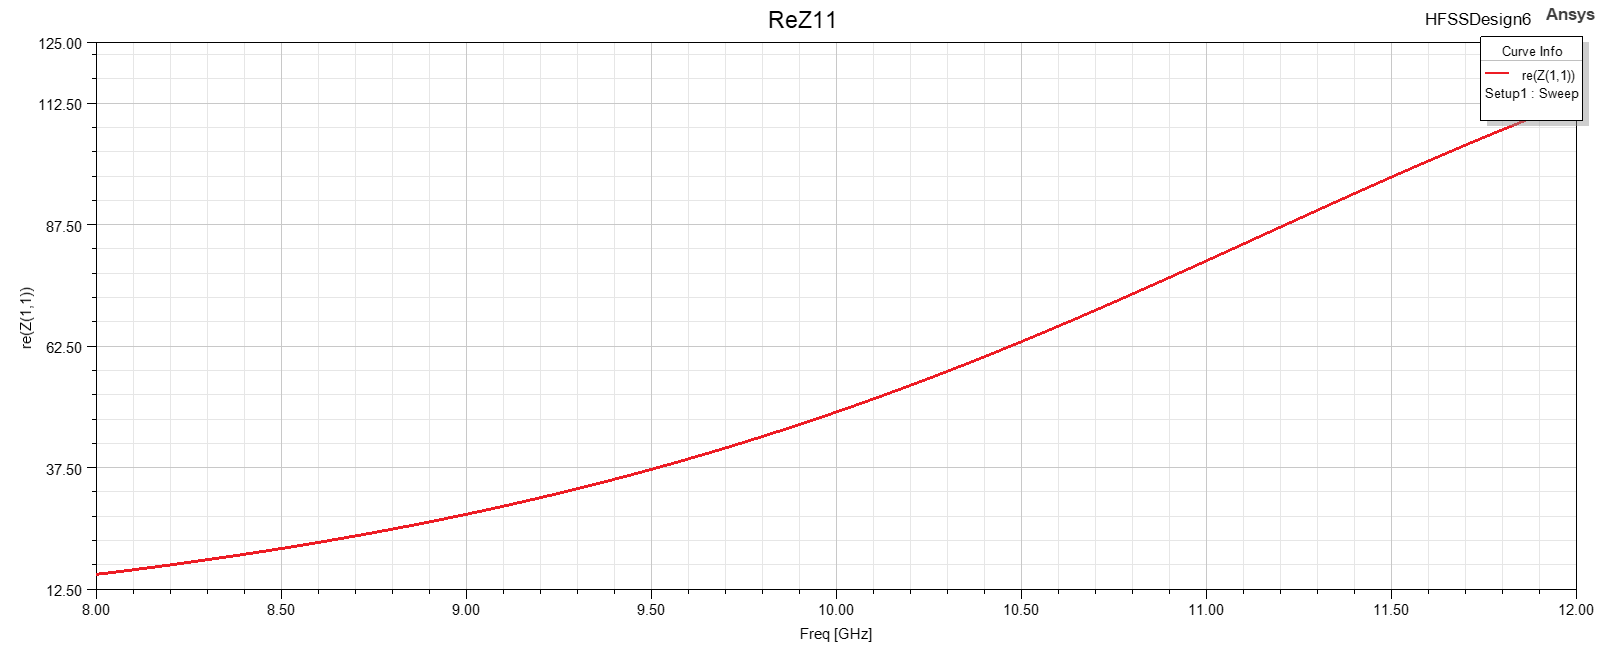
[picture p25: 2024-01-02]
imgs/exp2_reZ11.png

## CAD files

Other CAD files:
flange_96103722.dwg
e_plane_wr90_96103722.dwg
e_plane_WR_90.dwg
e_plane_WR_90 (2).dwg
